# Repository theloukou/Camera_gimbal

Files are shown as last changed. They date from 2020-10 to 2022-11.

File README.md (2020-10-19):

# 2-axis Camera Gimbal
Arduino-based 2-axis BLDC gimbal controller

This project consists the main study of my Thesis for my Bachelor of Science at the Department of Automation Engineering of the Piraeus University of Applied Sciences.

It is an Arduino Mega2560 based system, that consists of an extention PCB(shield) that acts as a motor driver for BLCD motors, and an interface between the Arduino and its peripheral devices (motor drivers, IMUs, switches, battery).
Microcontroller code is presented, as well as shield schematic/PCB layout/PCB Gerbers. Also, some 3D-Printed parts used around the gimbal frame are presented in STL form.

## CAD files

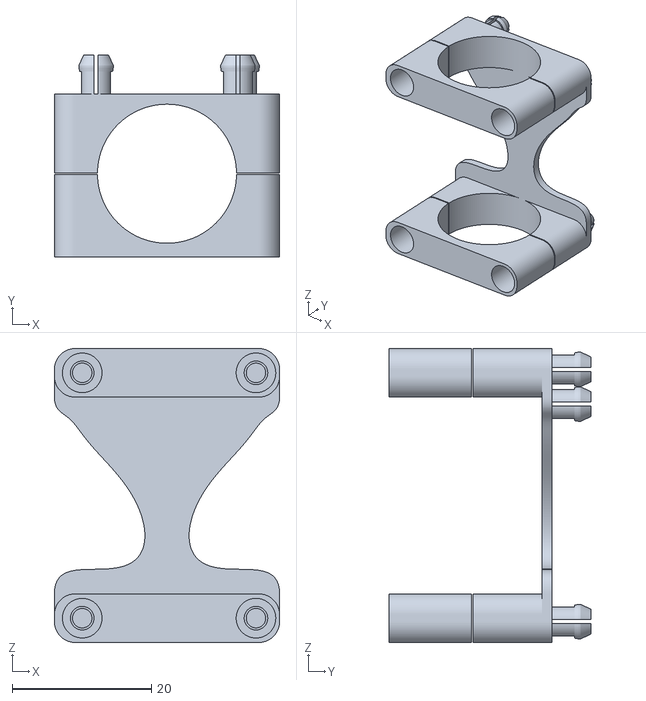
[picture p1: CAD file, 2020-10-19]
3D_prints/case_mount.stl
32.4 x 29.1 x 42.3

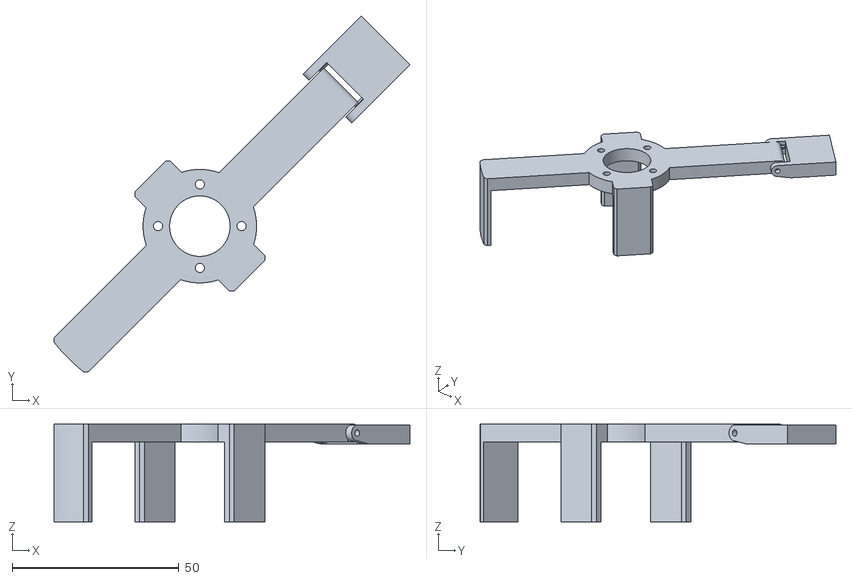
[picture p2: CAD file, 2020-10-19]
3D_prints/bat_holder.stl
106.6 x 106.6 x 29.3

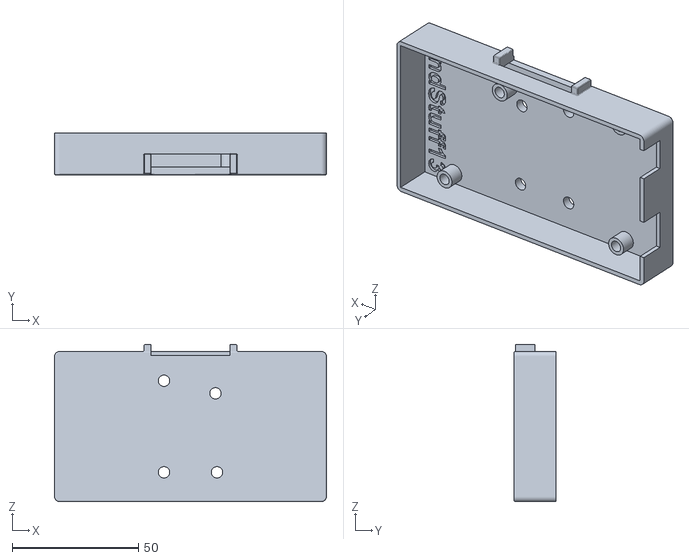
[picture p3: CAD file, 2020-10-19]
3D_prints/arduino_case.stl
107.8 x 16.6 x 62.3

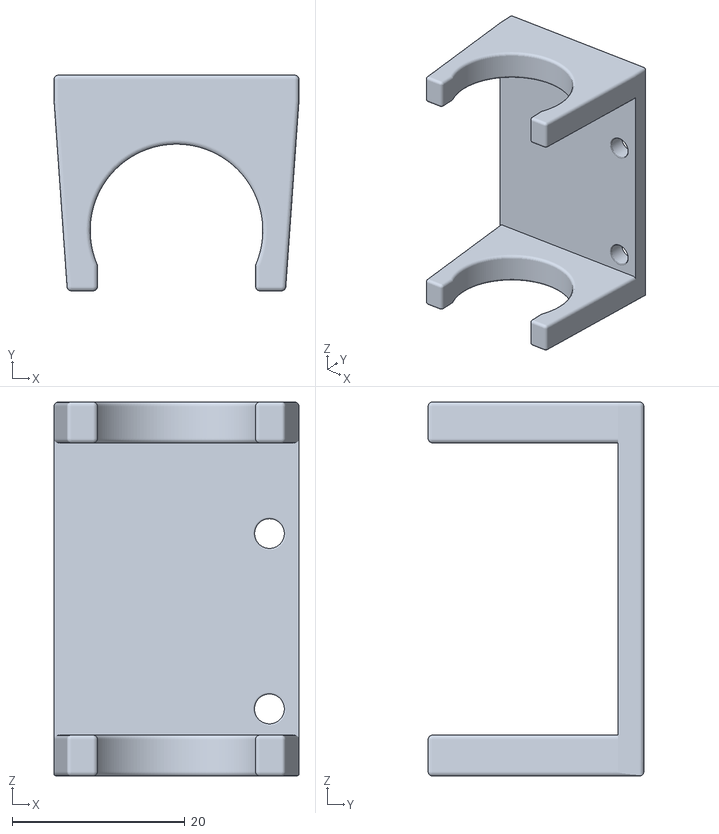
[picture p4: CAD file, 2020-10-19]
3D_prints/mpu_frame_base.stl
28.4 x 25.0 x 43.4

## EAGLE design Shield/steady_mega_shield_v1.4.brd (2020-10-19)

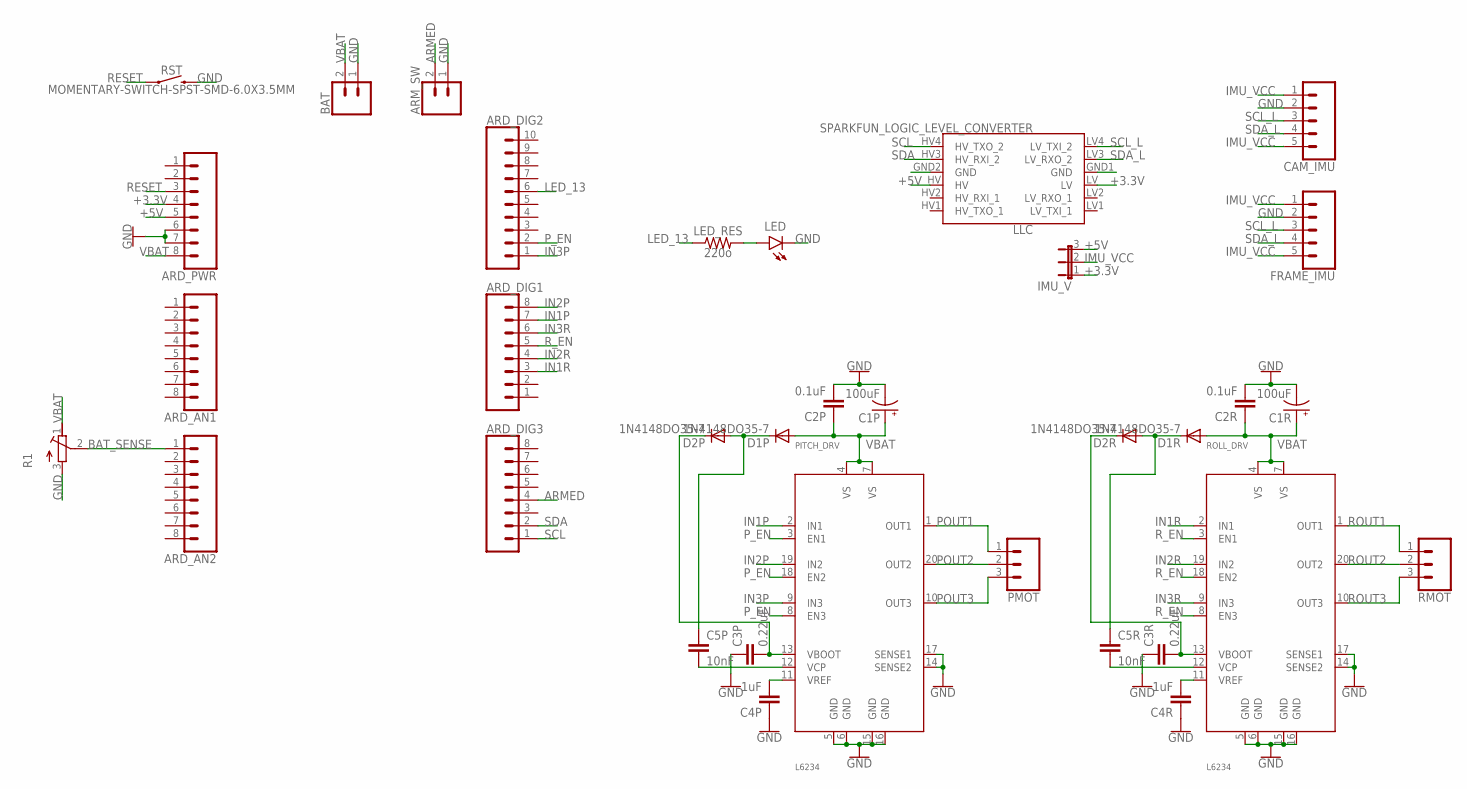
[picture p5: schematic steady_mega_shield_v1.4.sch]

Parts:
ARD_AN1, ARD_AN2: CONN_08"; 1X08
ARD_DIG1, ARD_DIG3: CONN_08"; 1X08
ARD_DIG2: CONN_10"; 1X10
ARD_PWR: CONN_08"; 1X08
ARM_SW: CONN_02; 1X02
BAT: CONN_02; 1X02
C1P, C1R: 100uF; CPOL-RADIAL-2.5MM-6.5MM
C2P, C2R: 0.1uF; C025-024X044
C3P, C3R: 0.22uF; C5B2.5
C4P, C4R: 1uF; C5B5.5
C5P, C5R: 10nF; C5B2.5
CAM_IMU: CONN_05JST; JST-5-PTH
D1P, D1R, D2P, D2R: 1N4148DO35-7; DO35-7
FRAME_IMU: CONN_05JST; JST-5-PTH
IMU_V: JP2E; JP2
LED: LED3MM; LED_3MM
LED_RES: 220o; 0805
LLC: SPARKFUN_LOGIC_LEVEL_CONVERTER
PITCH_DRV: L6234; DIL20
PMOT: CONN_03POLAR; MOLEX-1X3
R1: R-TRIMMT93XB; RTRIMT93XB
RMOT: CONN_03POLAR; MOLEX-1X3
ROLL_DRV: L6234; DIL20
RST: MOMENTARY-SWITCH-SPST-SMD-6.0X3.5MM; TACTILE_SWITCH_SMD_6.0X3.5MM

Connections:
+3.3V: ARD_PWR.4, IMU_V.1, LLC.LV
+5V: ARD_PWR.5, IMU_V.3, LLC.HV
ARMED: ARD_DIG3.4, ARM_SW.2
BAT_SENSE: ARD_AN2.1, R1.2 (S)
GND: ARD_PWR.6, ARD_PWR.7, ARM_SW.1, BAT.1, C1P.2 (-), C1R.2 (-), C2P.2, C2R.2, C3P.1, C3R.1, C4P.1, C4R.1, CAM_IMU.2, FRAME_IMU.2, LED.K (C), LLC.GND1 (GND), LLC.GND2 (GND), PITCH_DRV.5 (GND), PITCH_DRV.6 (GND), PITCH_DRV.14 (SENSE2), PITCH_DRV.15 (GND), PITCH_DRV.16 (GND), PITCH_DRV.17 (SENSE1), R1.3 (A), ROLL_DRV.5 (GND), ROLL_DRV.6 (GND), ROLL_DRV.14 (SENSE2), ROLL_DRV.15 (GND), ROLL_DRV.16 (GND), ROLL_DRV.17 (SENSE1), RST.2
IMU_VCC: CAM_IMU.1, CAM_IMU.5, FRAME_IMU.1, FRAME_IMU.5, IMU_V.2
IN1P: ARD_DIG1.7, PITCH_DRV.2 (IN1)
IN1R: ARD_DIG1.3, ROLL_DRV.2 (IN1)
IN2P: ARD_DIG1.8, PITCH_DRV.19 (IN2)
IN2R: ARD_DIG1.4, ROLL_DRV.19 (IN2)
IN3P: ARD_DIG2.1, PITCH_DRV.9 (IN3)
IN3R: ARD_DIG1.6, ROLL_DRV.9 (IN3)
LED_13: ARD_DIG2.6, LED_RES.1
unnamed: C4R.2, ROLL_DRV.11 (VREF)
unnamed: C4P.2, PITCH_DRV.11 (VREF)
unnamed: C5R.2, ROLL_DRV.12 (VCP)
unnamed: C3R.2, D2R.C, ROLL_DRV.13 (VBOOT)
unnamed: C5P.2, PITCH_DRV.12 (VCP)
unnamed: C3P.2, D2P.C, PITCH_DRV.13 (VBOOT)
unnamed: LED.A, LED_RES.2
unnamed: C5P.1, D1P.C, D2P.A
unnamed: C5R.1, D1R.C, D2R.A
POUT1: PITCH_DRV.1 (OUT1), PMOT.1
POUT2: PITCH_DRV.20 (OUT2), PMOT.2
POUT3: PITCH_DRV.10 (OUT3), PMOT.3
P_EN: ARD_DIG2.2, PITCH_DRV.3 (EN1), PITCH_DRV.8 (EN3), PITCH_DRV.18 (EN2)
RESET: ARD_PWR.3, RST.1
ROUT1: RMOT.1, ROLL_DRV.1 (OUT1)
ROUT2: RMOT.2, ROLL_DRV.20 (OUT2)
ROUT3: RMOT.3, ROLL_DRV.10 (OUT3)
R_EN: ARD_DIG1.5, ROLL_DRV.3 (EN1), ROLL_DRV.8 (EN3), ROLL_DRV.18 (EN2)
SCL: ARD_DIG3.1, LLC.HV4 (HV_TXO_2)
SCL_L: CAM_IMU.3, FRAME_IMU.3, LLC.LV4 (LV_TXI_2)
SDA: ARD_DIG3.2, LLC.HV3 (HV_RXI_2)
SDA_L: CAM_IMU.4, FRAME_IMU.4, LLC.LV3 (LV_RXO_2)
VBAT: ARD_PWR.8, BAT.2, C1P.1 (+), C1R.1 (+), C2P.1, C2R.1, D1P.A, D1R.A, PITCH_DRV.4 (VS), PITCH_DRV.7 (VS), R1.1 (E), ROLL_DRV.4 (VS), ROLL_DRV.7 (VS)

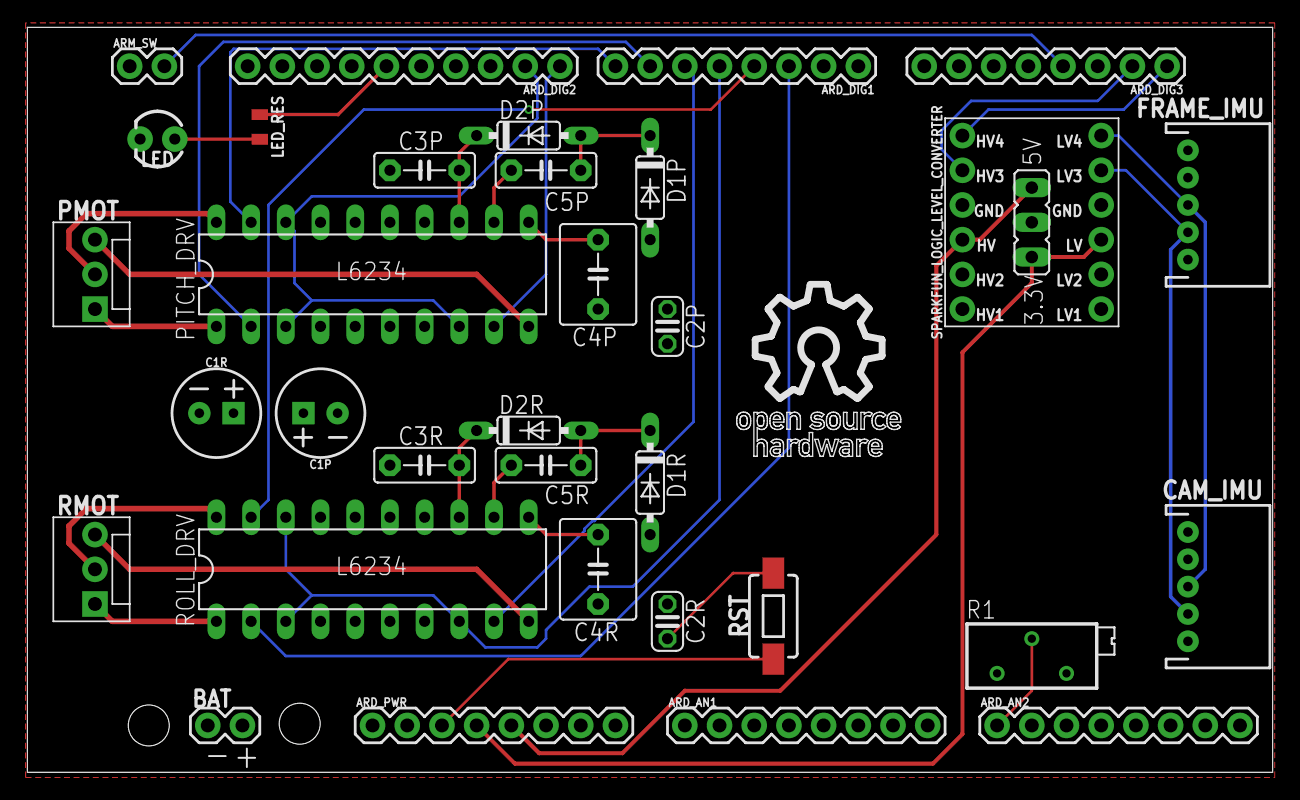
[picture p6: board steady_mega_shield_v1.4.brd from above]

Board: 4 copper layers, 91.2 x 54.5 mm, 34 parts (0 on the bottom side), 36 nets.

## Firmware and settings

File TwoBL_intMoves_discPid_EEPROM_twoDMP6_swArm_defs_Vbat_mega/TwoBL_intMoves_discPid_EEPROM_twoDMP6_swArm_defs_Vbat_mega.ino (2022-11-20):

/* ============================================
  I2Cdev device library code is placed under the MIT license
  Copyright (c) 2012 Jeff Rowberg

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
  THE SOFTWARE IS PROVIDED "AS IS", WITHOUT WARRANTY OF ANY KIND, EXPRESS OR
  IMPLIED, INCLUDING BUT NOT LIMITED TO THE WARRANTIES OF MERCHANTABILITY,
  FITNESS FOR A PARTICULAR PURPOSE AND NONINFRINGEMENT. IN NO EVENT SHALL THE
  AUTHORS OR COPYRIGHT HOLDERS BE LIABLE FOR ANY CLAIM, DAMAGES OR OTHER
  LIABILITY, WHETHER IN AN ACTION OF CONTRACT, TORT OR OTHERWISE, ARISING FROM,
  OUT OF OR IN CONNECTION WITH THE SOFTWARE OR THE USE OR OTHER DEALINGS IN
  THE SOFTWARE.
  ===============================================
*/

#include "Definitions.h"
#include "TimerOne.h"
#include "TimerFive.h"
#include "EEPROM.h"
#include "I2Cdev.h"
#include "MPU6050_6Axis_MotionApps_V6_12.h"
#if I2CDEV_IMPLEMENTATION == I2CDEV_ARDUINO_WIRE
#include "Wire.h"
#endif

//IMUs declaration
#ifdef CAM_MPU
MPU6050 camIMU;
#endif
#ifdef FR_MPU
MPU6050 frIMU(0x69);
#endif

// MPU control/status vars
#ifdef CAM_MPU
bool camIMUReady = false;  // set true if DMP init was successful
uint8_t camIMUdevStatus;      // return status after each device operation (0 = success, !0 = error)
uint16_t camIMUpacketSize;    // expected DMP packet size (default is 42 bytes)
uint16_t camIMUfifoCount;     // count of all bytes currently in FIFO
uint8_t camIMUfifoBuffer[64]; // FIFO storage buffer
#endif
#ifdef FR_MPU
bool frIMUReady = false;  // set true if DMP init was successful
uint8_t frIMUdevStatus;      // return status after each device operation (0 = success, !0 = error)
uint16_t frIMUpacketSize;    // expected DMP packet size (default is 42 bytes)
uint16_t frIMUfifoCount;     // count of all bytes currently in FIFO
uint8_t frIMUfifoBuffer[64]; // FIFO storage buffer
#endif

// orientation/motion vars
#ifdef CAM_MPU
Quaternion camIMUq;               // [w, x, y, z] quaternion container
VectorFloat camIMUgravity;        // [x, y, z]  gravity vector
float camIMUypr[3] = {0, 0, 0};   // [yaw, pitch, roll] yaw/pitch/roll container and gravity vector
#endif
#ifdef FR_MPU
Quaternion frIMUq;                // [w, x, y, z] quaternion container
VectorFloat frIMUgravity;         // [x, y, z]  gravity vector
float frIMUypr[3] = {0, 0, 0};    // [yaw, pitch, roll] yaw/pitch/roll container and gravity vector
#endif

//PID Vars
volatile double pitchSetpoint = 0, rollSetpoint = 0;
double camIMUpitch, frIMUpitch, pitchOutput;
double camIMUroll, frIMUroll, rollOutput;
double pitchKp, pitchKi, pitchKd;
double rollKp, rollKi, rollKd;
byte PIDbound;

//rest of vars
char pitchDir = 1, rollDir = 1;
String serialStr;
unsigned long pitchIntPeriod = 10;  //initial pitch int period in msec
unsigned long rollIntPeriod = 10;   //initial roll int period in msec
bool ledState = false;
bool intTriggered = false;
byte ledCount = 0;
unsigned int batCount = 0;
unsigned int LedBlinkTime = 100; //1000msec, based on 100Hz interrupt

// ================================================================
// ===                      INITIAL SETUP                       ===
// ================================================================
void setup() {
  //reserve memory for variable length serial commands
  serialStr.reserve(40);

  //FAST PWM
#ifdef FAST_PWM
  TCCR3A = _BV(WGM30);
  TCCR4A = _BV(WGM40);
#endif

  //PhaseCorrect PWM
#ifdef PHASE_PWM
  TCCR3A = _BV(WGM30);
  TCCR3B = _BV(WGM32);
  TCCR4A = _BV(WGM40);
  TCCR4B = _BV(WGM42);
#endif

  //Set Timer 3&4 prescalers to 0 || motor PWM frequency = 31372.55 Hz
  TCCR3B = TCCR3B & 0b11111000 | 0x01;
  TCCR4B = TCCR4B & 0b11111000 | 0x01;

  //pin mode declarations
  pinMode(ROLLOUT1, OUTPUT);
  pinMode(ROLLOUT2, OUTPUT);
  pinMode(ROLLOUT3, OUTPUT);
  pinMode(PITCHOUT1, OUTPUT);
  pinMode(PITCHOUT2, OUTPUT);
  pinMode(PITCHOUT3, OUTPUT);
  pinMode(ENROLL, OUTPUT);
  pinMode(ENPITCH, OUTPUT);
  pinMode(ARMSW, INPUT_PULLUP);
  pinMode(LED, OUTPUT);

#ifdef SERIAL_ENABLED
  // initialize serial communication
  Serial.begin(115200);
  Serial.println("Ready!");
#endif

  //setup Timer2 for 100Hz interrupt
  //  TCCR2A = 0;
  TCCR2A = _BV(WGM21);
  //  TCCR2B = 0;
  TCCR2B = TCCR2B & 0b11111000 | 0x07;
  TCNT2 = 0;
  OCR2A = 155; // = (16*10^6)/(1024*Hz)-1 < 256
  TIMSK2 = _BV(OCIE2A);

  //attach arm switch interrupt
  attachInterrupt(digitalPinToInterrupt(ARMSW), switched, CHANGE);

  // join I2C bus (I2Cdev library doesn't do this automatically)
  Wire.begin();
  Wire.setClock(400000); // 400kHz I2C clock.

  //initialise IMUs
#ifdef CAM_MPU
  cameraIMUsetup();
#endif
#ifdef FR_MPU
  frameIMUsetup();
#endif

  //disarm motors
  disarm();

  //initialize motor interrupt timers
  Timer1.initialize(rollIntPeriod * 1000);
  Timer5.initialize(pitchIntPeriod * 1000);

  //PID initialization
  eeprom_get();
  calcK();

#ifdef SERIAL_ENABLED
  //printout Serial commands, wait 4sec for user to read
  serialCommandsPrint();
  delay(1000);
#endif

  Serial.println("Starting");

  //get initial Vbat
  voltage();

  //print PID settings
  serialSettingsPrint();

  //reset IMU FIFOs for clean start
#ifdef CAM_MPU
  camIMU.resetFIFO();
#endif
#ifdef FR_MPU
  frIMU.resetFIFO();
#endif
}

// ================================================================
// ===                    MAIN PROGRAM LOOP                     ===
// ================================================================
void loop() {
  // if IMU programming failed, don't try to do anything
#ifdef CAM_MPU
  if (!camIMUReady) return;  //halt if MPU is missing
#endif
#ifdef FR_MPU
  if (!frIMUReady) return;  //halt if MPU is missing
#endif


  if (intTriggered) {
    //get IMU data, calculate PIDs
#ifdef CAM_MPU
    cameraIMUdata();
    PIDcalc(camIMUpitch, pitchSetpoint, &pitchOutput, camIMUroll, rollSetpoint, &rollOutput);
#endif
#ifdef FR_MPU
    frameIMUdata();
    PIDcalc(frIMUpitch, pitchSetpoint, &pitchOutput, frIMUroll, rollSetpoint, &rollOutput);
#endif

    //decode PID outputs into motor driving signals
    pitchOutDecode(pitchOutput);
    rollOutDecode(rollOutput);

    //serial print IMU data
#ifdef DATAOUT
    serialDataPrint();
#endif

    //increment status counters
    ledCount++;
    batCount++;

    intTriggered = false;
  }

  //LED blink routine
  if (ledCount >= LedBlinkTime) {
    ledState = !ledState;
    digitalWrite(LED, ledState);
    ledCount = 0;
  }

  //check Vbat
  if (batCount >= VBATCHECKTIME) {
    voltage();
    batCount = 0;
  }
}

//Timer2 interrupt routine
ISR(TIMER2_COMPA_vect) {
  intTriggered = true;
}

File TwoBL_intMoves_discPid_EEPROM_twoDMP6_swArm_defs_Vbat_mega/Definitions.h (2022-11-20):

#define SERIAL_ENABLED
#ifdef SERIAL_ENABLED
#define DATAOUT
#define VBATSERIAL
//#define JSON
#endif
//#define USE_OLD_DMPGETYAWPITCHROLL

#define NO_CALIBRATION

#define FAST_PWM
//#define PHASE_PWM

#define CAM_MPU
//#define FR_MPU

//pin names
#define ROLLOUT1 5
#define ROLLOUT2 3
#define ROLLOUT3 2
#define PITCHOUT1 6
#define PITCHOUT2 7
#define PITCHOUT3 8
#define ENROLL 4
#define ENPITCH 9
#define ARMSW 18
#define LED 13

//BL_vars
//#define STEPS 255
#define STEPS 360
#define STARTINGOFFSET 100

#define VBATCHECKTIME 3000  ///30sec, based on 100Hz interrupt

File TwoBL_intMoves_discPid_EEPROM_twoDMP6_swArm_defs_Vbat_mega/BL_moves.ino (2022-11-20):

//255 PWM sine table
//const byte matrix[] = {128, 131, 134, 137, 140, 143, 146, 149, 153, 156, 159, 162, 165, 168, 171, 174, 177, 180, 182,
//                       185, 188, 191, 194, 196, 199, 201, 204, 206, 209, 211, 214, 216, 218, 220, 223, 225, 227, 229,
//                       230, 232, 234, 236, 237, 239, 240, 242, 243, 245, 246, 247, 248, 249, 250, 251, 251, 252, 253,
//                       253, 254, 254, 255, 255, 255, 255, 255, 255, 255, 255, 254, 254, 253, 253, 252, 251, 251, 250,
//                       249, 248, 247, 246, 245, 243, 242, 240, 239, 237, 236, 234, 232, 230, 229, 227, 225, 223, 220,
//                       218, 216, 214, 211, 209, 206, 204, 201, 199, 196, 194, 191, 188, 185, 182, 180, 177, 174, 171,
//                       168, 165, 162, 159, 156, 153, 149, 146, 143, 140, 137, 134, 131, 128, 124, 121, 118, 115, 112,
//                       109, 106, 102, 99, 96, 93, 90, 87, 84, 81, 78, 75, 73, 70, 67, 64, 61, 59, 56,
//                       54, 51, 49, 46, 44, 41, 39, 37, 35, 32, 30, 28, 26, 25, 23, 21, 19, 18, 16,
//                       15, 13, 12, 10, 9, 8, 7, 6, 5, 4, 4, 3, 2, 2, 1, 1, 0, 0, 0,
//                       0, 0, 0, 0, 0, 1, 1, 2, 2, 3, 4, 4, 5, 6, 7, 8, 9, 10, 12,
//                       13, 15, 16, 18, 19, 21, 23, 25, 26, 28, 30, 32, 35, 37, 39, 41, 44, 46, 49,
//                       51, 54, 56, 59, 61, 64, 67, 70, 73, 75, 78, 81, 84, 87, 90, 93, 96, 99, 102,
//                       106, 109, 112, 115, 118, 121, 124, 127
//                      };

//360 PWM sine table
const byte matrix[] = {128, 130, 132, 134, 136, 139, 141, 143, 145, 148, 150, 152, 154, 156, 158, 161, 163, 165, 167, 169, 171,
                       173, 175, 177, 179, 182, 184, 186, 188, 189, 191, 193, 195, 197, 199, 201, 203, 204, 206, 208, 210, 211,
                       213, 215, 216, 218, 219, 221, 222, 224, 225, 227, 228, 230, 231, 232, 233, 235, 236, 237, 238, 239, 240,
                       241, 242, 243, 244, 245, 246, 247, 247, 248, 249, 250, 250, 251, 251, 252, 252, 253, 253, 254, 254, 254,
                       254, 255, 255, 255, 255, 255, 255, 255, 255, 255, 255, 254, 254, 254, 254, 253, 253, 253, 252, 252, 251,
                       250, 250, 249, 249, 248, 247, 246, 245, 245, 244, 243, 242, 241, 240, 239, 238, 236, 235, 234, 233, 231,
                       230, 229, 227, 226, 225, 223, 222, 220, 219, 217, 215, 214, 212, 210, 209, 207, 205, 204, 202, 200, 198,
                       196, 194, 192, 190, 188, 187, 185, 183, 181, 178, 176, 174, 172, 170, 168, 166, 164, 162, 160, 157, 155,
                       153, 151, 149, 146, 144, 142, 140, 138, 135, 133, 131, 129, 126, 124, 122, 120, 117, 115, 113, 111, 109,
                       106, 104, 102, 100, 98, 95, 93, 91, 89, 87, 85, 83, 81, 79, 77, 74, 72, 70, 68, 67, 65,
                       63, 61, 59, 57, 55, 53, 51, 50, 48, 46, 45, 43, 41, 40, 38, 36, 35, 33, 32, 30, 29,
                       28, 26, 25, 24, 22, 21, 20, 19, 17, 16, 15, 14, 13, 12, 11, 10, 10, 9, 8, 7, 6,
                       6, 5, 5, 4, 3, 3, 2, 2, 2, 1, 1, 1, 1, 0, 0, 0, 0, 0, 0, 0, 0,
                       0, 0, 1, 1, 1, 1, 2, 2, 3, 3, 4, 4, 5, 5, 6, 7, 8, 8, 9, 10, 11,
                       12, 13, 14, 15, 16, 17, 18, 19, 20, 22, 23, 24, 25, 27, 28, 30, 31, 33, 34, 36, 37,
                       39, 40, 42, 44, 45, 47, 49, 51, 52, 54, 56, 58, 60, 62, 64, 66, 67, 69, 71, 73, 76,
                       78, 80, 82, 84, 86, 88, 90, 92, 94, 97, 99, 101, 103, 105,  107, 110, 112, 114, 116, 119, 121,
                       123, 125, 127
                      };

byte maxPwm = 255;

//initialize motor phase startings
volatile int pitchOnePos = 0 + STARTINGOFFSET;
volatile int pitchTwoPos = (STEPS / 3) + STARTINGOFFSET;
volatile int pitchThreePos = ((STEPS / 3) * 2) + STARTINGOFFSET;
volatile int rollOnePos = 0 + STARTINGOFFSET;
volatile int rollTwoPos = (STEPS / 3) + STARTINGOFFSET;
volatile int rollThreePos = ((STEPS / 3) * 2) + STARTINGOFFSET;

//arm switch interrupt routine
void switched() {
  if (!digitalRead(ARMSW)) {
    disarm();
  }
  else {
    arm();
  }
}

// motor arm routine
void arm() {
  digitalWrite(ENPITCH, 1);
  digitalWrite(ENROLL, 1);
  Timer1.attachInterrupt(rollPos);
  Timer5.attachInterrupt(pitchPos);
  PIDzero();
}

// motor disarm routine
void disarm() {
  digitalWrite(ENPITCH, 0);
  digitalWrite(ENROLL, 0);
  Timer1.detachInterrupt();
  Timer5.detachInterrupt();
}

//PID output decoders
void rollOutDecode(double output) {
  if (signbit(output)) rollDir = -1;
  else rollDir = 1;;

  rollIntPeriod = 1 / (abs(output)) * 100000;
  if (rollIntPeriod == 0) rollIntPeriod = 1000000;
  Timer1.setPeriod(rollIntPeriod);
}

void pitchOutDecode(double output) {
  if (signbit(output)) pitchDir = -1;
  else pitchDir = 1;

  pitchIntPeriod = 1 / (abs(output)) * 100000;
  if (pitchIntPeriod == 0) pitchIntPeriod = 1000000;
  Timer5.setPeriod(pitchIntPeriod);
}

//roll motor drive
void rollPos() {
  rollOnePos += rollDir;
  rollTwoPos += rollDir;
  rollThreePos += rollDir;

  if (rollOnePos >= STEPS) {
    rollOnePos -= STEPS;
  }
  else if (rollOnePos <= -1) {
    rollOnePos += STEPS;
  }
  if (rollTwoPos >= STEPS) {
    rollTwoPos -= STEPS;
  }
  else if (rollTwoPos <= -1) {
    rollTwoPos += STEPS;
  }
  if (rollThreePos >= STEPS) {
    rollThreePos -= STEPS;
  }
  else if (rollThreePos <= -1) {
    rollThreePos += STEPS;
  }

  analogWrite(ROLLOUT1, matrix[rollOnePos]);
  analogWrite(ROLLOUT2, matrix[rollTwoPos]);
  analogWrite(ROLLOUT3, matrix[rollThreePos]);
}

//pitch motor drive
void pitchPos() {
  pitchOnePos += pitchDir;
  pitchTwoPos += pitchDir;
  pitchThreePos += pitchDir;

  if (pitchOnePos >= STEPS) {
    pitchOnePos -= STEPS;
  }
  else if (pitchOnePos <= -1) {
    pitchOnePos += STEPS;
  }
  if (pitchTwoPos >= STEPS) {
    pitchTwoPos -= STEPS;
  }
  else if (pitchTwoPos <= -1) {
    pitchTwoPos += STEPS;
  }
  if (pitchThreePos >= STEPS) {
    pitchThreePos -= STEPS;
  }
  else if (pitchThreePos <= -1) {
    pitchThreePos += STEPS;
  }

  analogWrite(PITCHOUT1, matrix[pitchOnePos]);
  analogWrite(PITCHOUT2, matrix[pitchTwoPos]);
  analogWrite(PITCHOUT3, matrix[pitchThreePos]);
}

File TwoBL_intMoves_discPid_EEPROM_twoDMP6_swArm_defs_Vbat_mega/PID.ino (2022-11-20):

//local PID vars
double pitchOutputDelta, pitchError = 0, pitchErrorPrev1 = 0, pitchErrorPrev2 = 0;
double rollOutputDelta, rollError = 0, rollErrorPrev1 = 0, rollErrorPrev2 = 0;
double pitchK1, pitchK2, pitchK3;
double rollK1, rollK2, rollK3;

//PID calculation
void PIDcalc(double Pinput, double Psetpoint, double *Poutput, double Rinput, double Rsetpoint, double *Routput) {

  pitchErrorPrev2 = pitchErrorPrev1;
  pitchErrorPrev1 = pitchError;
  pitchError = Psetpoint - Pinput;
  pitchOutputDelta = pitchK1 * pitchError + pitchK2 * pitchErrorPrev1 + pitchK3 * pitchErrorPrev2;
  *Poutput = constrain(*Poutput - pitchOutputDelta, -PIDbound, PIDbound);

  rollErrorPrev2 = rollErrorPrev1;
  rollErrorPrev1 = rollError;
  rollError = Rsetpoint - Rinput;
  rollOutputDelta = rollK1 * rollError + rollK2 * rollErrorPrev1 + rollK3 * rollErrorPrev2;
  *Routput = constrain(*Routput - rollOutputDelta, -PIDbound, PIDbound);
}

//Calculate local gains
void calcK() {
  pitchK1 = pitchKp + pitchKi + pitchKd;
  pitchK2 = -pitchKp - (2 * pitchKd);
  pitchK3 = pitchKd;

  rollK1 = rollKp + rollKi + rollKd;
  rollK2 = -rollKp - (2 * rollKd);
  rollK3 = rollKd;
}

//Zero PID vars
void PIDzero() {
  pitchOutput = 0; pitchError = 0; pitchErrorPrev1 = 0; pitchErrorPrev2 = 0;
  rollOutput = 0; rollError = 0;  rollErrorPrev1 = 0;  rollErrorPrev2 = 0;
}

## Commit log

2022-11-20 Added gimbal calibration helper/data visualizer
2022-11-20 Switched to discrete PID, updates for json serial output, support for helper utility

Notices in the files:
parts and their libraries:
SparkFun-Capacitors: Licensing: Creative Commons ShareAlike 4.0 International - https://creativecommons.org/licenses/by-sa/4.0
